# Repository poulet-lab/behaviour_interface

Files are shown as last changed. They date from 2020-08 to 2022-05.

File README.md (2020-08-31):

# Behavior Interface

Interface between a data acquisition device on one end as well as, both,
1) input from capacitive lick sensors, and
2) reward output to valves on the other end.

Digital events (licks, rewards) are displayed by means of LEDs.
Circuit breakers can be used to reset the capacitive sensors.

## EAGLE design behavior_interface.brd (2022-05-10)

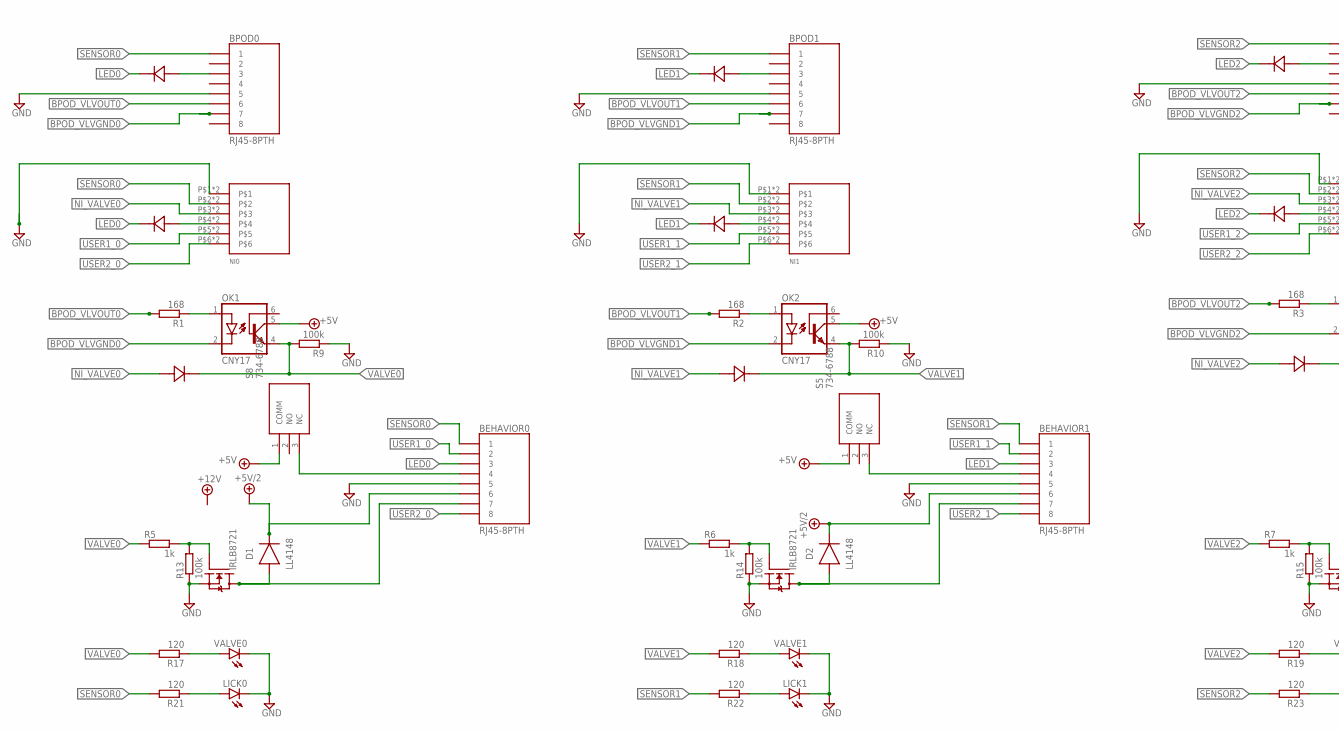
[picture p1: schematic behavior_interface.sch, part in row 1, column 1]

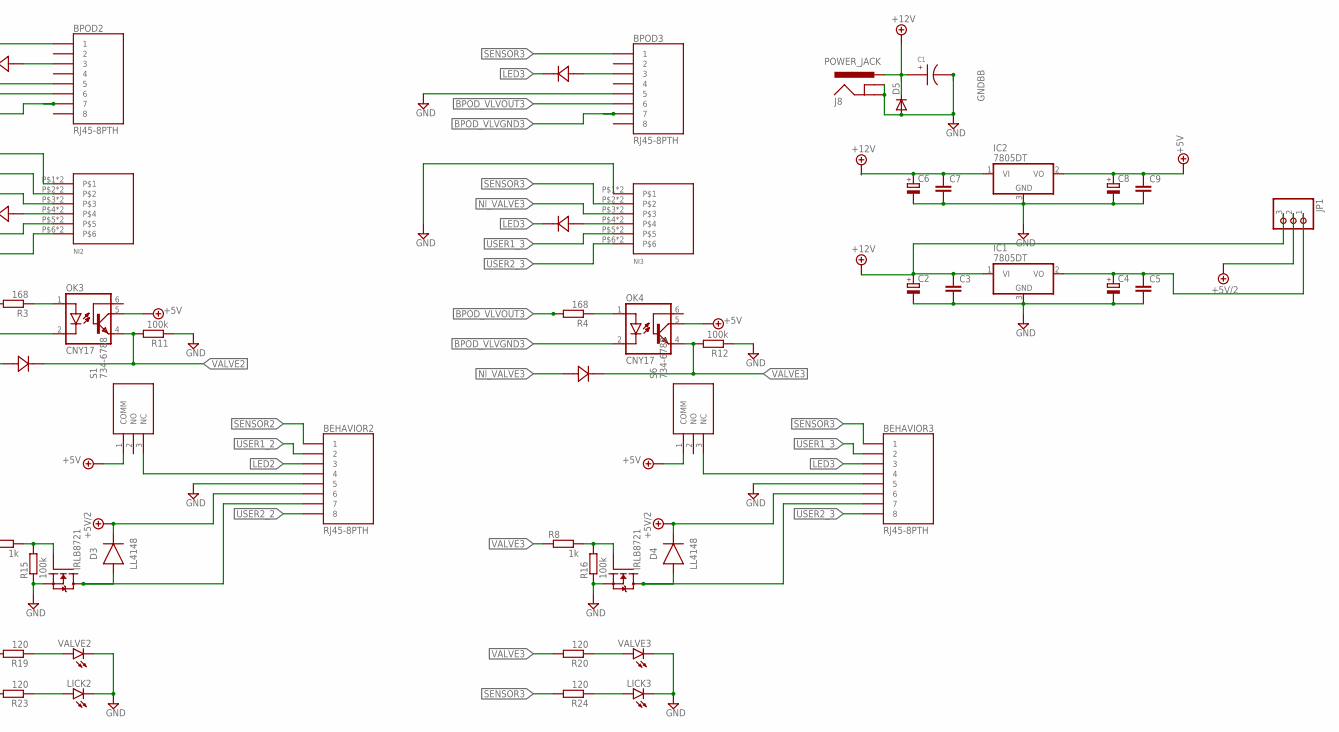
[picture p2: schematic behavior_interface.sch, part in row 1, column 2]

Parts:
BEHAVIOR0, BEHAVIOR1, BEHAVIOR2, BEHAVIOR3: RJ45-8PTH; RJ45-8
BPOD0, BPOD1, BPOD2, BPOD3: RJ45-8PTH; RJ45-8
C1: EEE-FK1H100UR
C2, C4, C6, C8: CPOL-EUD; PANASONIC_D
C3, C5, C7, C9: C-EUC1206; C1206
CR1, CR2, CR3, CR4, CR5, CR6, CR7, CR8, CR9, CR10, CR11, CR12: CUS10S30USC_TOS-M; USC_TOS-M
D1, D2, D3, D4: LL4148; DIOMELF3516
D5: DIODE-DO214AA; DO214AA
IC1, IC2: 7805DT; TO252
J8: POWER_JACK; POWER_JACK_PTH
JP1: PINHD-1X3; 1X03
LICK0, LICK1, LICK2, LICK3: LEDSIDELED; OSRAM-SIDELED
NI0, NI1, NI2, NI3: 1-2834015-6
OK1, OK2, OK3, OK4: CNY17; DIL06
R1, R2, R3, R4: 168; M1206
R5, R6, R7, R8: 1k; M1206
R9, R10, R11, R12, R13, R14, R15, R16: 100k; M1206
R17, R18, R19, R20, R21, R22, R23, R24: 120; M1206
S1, S5, S6, S8: 734-6788; 7346788
SETUP1, SETUP2, SETUP3, SETUP4: IRLB8721; TO220V
VALVE0, VALVE1, VALVE2, VALVE3: LEDSIDELED; OSRAM-SIDELED

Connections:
+5V: C8.+, C9.1, IC2.2 (VO), OK1.5 (COL), OK2.5 (COL), OK3.5 (COL), OK4.5 (COL), S1.1 (COMM), S5.1 (COMM), S6.1 (COMM), S8.1 (COMM)
+5V/2: BEHAVIOR0.6, BEHAVIOR1.6, BEHAVIOR2.6, BEHAVIOR3.6, D1.1 (C), D2.1 (C), D3.1 (C), D4.1 (C), JP1.2
+12V: C1.ANODE, C2.+, C3.1, C6.+, C7.1, D5.C, IC1.1 (VI), IC2.1 (VI), J8.PWR, JP1.3
BPOD_VLVGND0: BPOD0.7, OK1.2 (C)
BPOD_VLVGND1: BPOD1.7, OK2.2 (C)
BPOD_VLVGND2: BPOD2.7, OK3.2 (C)
BPOD_VLVGND3: BPOD3.7, OK4.2 (C)
BPOD_VLVOUT0: BPOD0.6, R1.2
BPOD_VLVOUT1: BPOD1.6, R2.2
BPOD_VLVOUT2: BPOD2.6, R3.2
BPOD_VLVOUT3: BPOD3.6, R4.2
GND: BEHAVIOR0.5, BEHAVIOR1.5, BEHAVIOR2.5, BEHAVIOR3.5, BPOD0.5, BPOD1.5, BPOD2.5, BPOD3.5, C1.CATHODE, C2.-, C3.2, C4.-, C5.2, C6.-, C7.2, C8.-, C9.2, D5.A, IC1.3 (GND), IC2.3 (GND), J8.GND, J8.GNDBREAK, LICK0.C, LICK1.C, LICK2.C, LICK3.C, NI0.P$1, NI0.P$7, NI1.P$1, NI1.P$7, NI2.P$1, NI2.P$7, NI3.P$1, NI3.P$7, R9.1, R10.1, R11.1, R12.1, R13.1, R14.1, R15.1, R16.1, SETUP1.3 (S), SETUP2.3 (S), SETUP3.3 (S), SETUP4.3 (S), VALVE0.C, VALVE1.C, VALVE2.C, VALVE3.C
LED0: BEHAVIOR0.3, CR1.1 (CATHODE), CR5.1 (CATHODE)
LED1: BEHAVIOR1.3, CR2.1 (CATHODE), CR6.1 (CATHODE)
LED2: BEHAVIOR2.3, CR3.1 (CATHODE), CR7.1 (CATHODE)
LED3: BEHAVIOR3.3, CR4.1 (CATHODE), CR8.1 (CATHODE)
unnamed: R5.2, R13.2, SETUP1.1 (G)
unnamed: CR5.2 (ANODE), NI0.P$4, NI0.P$10
unnamed: CR8.2 (ANODE), NI3.P$4, NI3.P$10
unnamed: BEHAVIOR0.7, D1.2 (A), SETUP1.2 (D)
unnamed: BEHAVIOR0.4, S8.3 (NC)
unnamed: OK1.1 (A), R1.1
unnamed: BPOD0.3, CR1.2 (ANODE)
unnamed: CR6.2 (ANODE), NI1.P$4, NI1.P$10
unnamed: LICK0.A, R21.1
unnamed: R17.1, VALVE0.A
unnamed: R6.2, R14.2, SETUP2.1 (G)
unnamed: BEHAVIOR1.7, D2.2 (A), SETUP2.2 (D)
unnamed: BEHAVIOR1.4, S5.3 (NC)
unnamed: OK2.1 (A), R2.1
unnamed: BPOD1.3, CR2.2 (ANODE)
unnamed: CR7.2 (ANODE), NI2.P$4, NI2.P$10
unnamed: LICK1.A, R22.1
unnamed: R18.1, VALVE1.A
unnamed: R7.2, R15.2, SETUP3.1 (G)
unnamed: BEHAVIOR2.7, D3.2 (A), SETUP3.2 (D)
unnamed: BEHAVIOR2.4, S1.3 (NC)
unnamed: OK3.1 (A), R3.1
unnamed: BPOD2.3, CR3.2 (ANODE)
unnamed: LICK2.A, R23.1
unnamed: R19.1, VALVE2.A
unnamed: C4.+, C5.1, IC1.2 (VO), JP1.1
unnamed: R8.2, R16.2, SETUP4.1 (G)
unnamed: BEHAVIOR3.7, D4.2 (A), SETUP4.2 (D)
unnamed: BEHAVIOR3.4, S6.3 (NC)
unnamed: OK4.1 (A), R4.1
unnamed: BPOD3.3, CR4.2 (ANODE)
unnamed: LICK3.A, R24.1
unnamed: R20.1, VALVE3.A
NI_VALVE0: CR9.2 (ANODE), NI0.P$3, NI0.P$9
NI_VALVE1: CR10.2 (ANODE), NI1.P$3, NI1.P$9
NI_VALVE2: CR11.2 (ANODE), NI2.P$3, NI2.P$9
NI_VALVE3: CR12.2 (ANODE), NI3.P$3, NI3.P$9
SENSOR0: BEHAVIOR0.1, BPOD0.1, NI0.P$2, NI0.P$8, R21.2
SENSOR1: BEHAVIOR1.1, BPOD1.1, NI1.P$2, NI1.P$8, R22.2
SENSOR2: BEHAVIOR2.1, BPOD2.1, NI2.P$2, NI2.P$8, R23.2
SENSOR3: BEHAVIOR3.1, BPOD3.1, NI3.P$2, NI3.P$8, R24.2
USER1_0: BEHAVIOR0.2, NI0.P$5, NI0.P$11
USER1_1: BEHAVIOR1.2, NI1.P$5, NI1.P$11
USER1_2: BEHAVIOR2.2, NI2.P$5, NI2.P$11
USER1_3: BEHAVIOR3.2, NI3.P$5, NI3.P$11
USER2_0: BEHAVIOR0.8, NI0.P$6, NI0.P$12
USER2_1: BEHAVIOR1.8, NI1.P$6, NI1.P$12
USER2_2: BEHAVIOR2.8, NI2.P$6, NI2.P$12
USER2_3: BEHAVIOR3.8, NI3.P$6, NI3.P$12
VALVE0: CR9.1 (CATHODE), OK1.4 (EMI), R5.1, R9.2, R17.2
VALVE1: CR10.1 (CATHODE), OK2.4 (EMI), R6.1, R10.2, R18.2
VALVE2: CR11.1 (CATHODE), OK3.4 (EMI), R7.1, R11.2, R19.2
VALVE3: CR12.1 (CATHODE), OK4.4 (EMI), R8.1, R12.2, R20.2

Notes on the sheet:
GNDBB

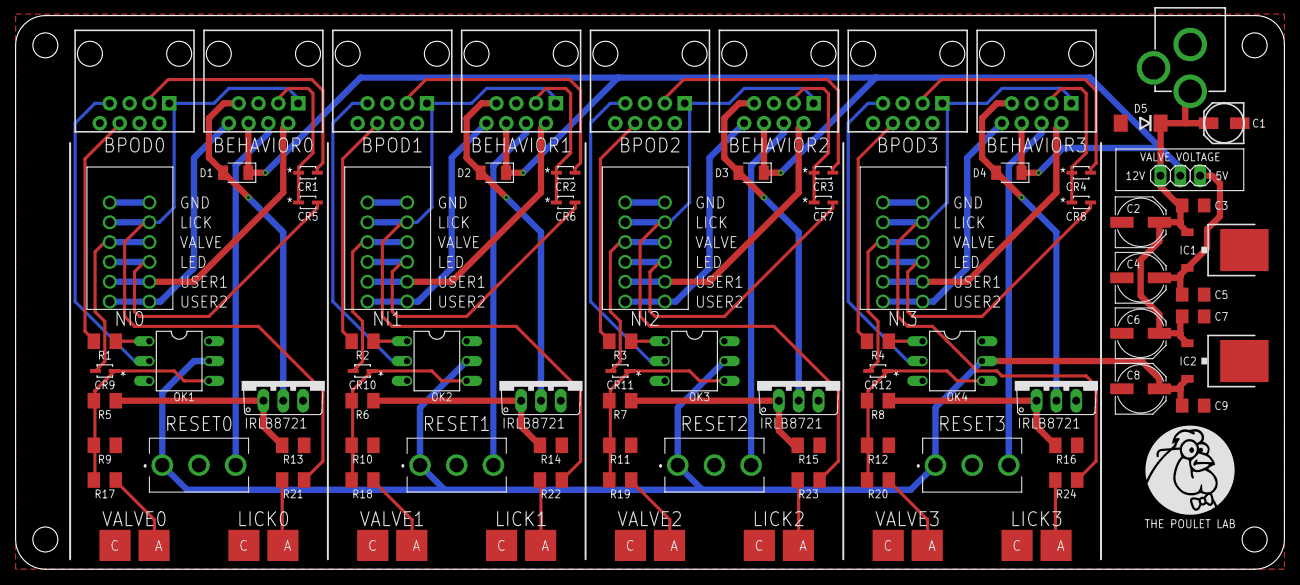
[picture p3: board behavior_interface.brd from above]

Board: 2 copper layers, 162.6 x 70.9 mm, 86 parts (0 on the bottom side), 69 nets.

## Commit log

2022-05-10 update to latest version
    [behavior_interface.brd, behavior_interface.sch]
2022-05-10 update enclosure

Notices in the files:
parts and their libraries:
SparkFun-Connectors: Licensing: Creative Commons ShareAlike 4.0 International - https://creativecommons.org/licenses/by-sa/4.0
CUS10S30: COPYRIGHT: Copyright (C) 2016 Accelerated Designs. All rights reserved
